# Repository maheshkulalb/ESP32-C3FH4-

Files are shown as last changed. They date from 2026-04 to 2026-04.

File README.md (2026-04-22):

# ESP32-C3FH4 Development Board (External Antenna)

ESP1
ESP2
ESP3

## Overview
This repository contains the complete open-source hardware design for a custom development board based on the Espressif **ESP32-C3FH4** SoC (RISC-V 32-bit single-core, integrated 4MB Flash). 

Unlike standard modules that rely on a PCB trace antenna, this design specifically routes the RF path to an external antenna connector , making it ideal for deployments inside metal enclosures or applications requiring higher-gain antennas. 

## Key Features
* **Microcontroller:** ESP32-C3FH4 (RISC-V 32-bit, 160MHz, built-in 4MB Flash)
* **Connectivity:** 2.4 GHz Wi-Fi and Bluetooth 5 (LE)
* **RF Interface:** connector with impedance-matched 50Ω RF routing
* **USB Interface:** USB Type-C for power and direct Serial flashing
* **Power Supply:** 5V to 3.3V LDO regulator 
* **I/O Breakout:** Standard 2.54mm pitch headers 
* **User Interface:** Reset button, User Boot button (GPIO9)

## EDA Tool & Source Files
This project is designed entirely in **KiCad** 

The native KiCad project files are included, allowing you to modify the schematics, tweak the PCB layout, or export custom manufacturing files.

### Repository Structure
* `/Hardware` - Native KiCad project files (`.kicad_pro`, `.kicad_sch`, `.kicad_pcb`)
* `/Gerbers` - Ready-to-manufacture Gerber and Drill files

**Recommended Fabrication Specs:**
* **Layers:4**
* **Thickness:1.57mm**
* **Impedance Control:Yes**

You are free to use, modify, and distribute this design

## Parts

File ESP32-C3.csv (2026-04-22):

Reference | Qty | Value | DNP | Exclude from BOM | Exclude from Board | Metric | Part Number
C1 | 1 | 1.8pF 6.3V (0.1pF) |  |  |  | Capacitor_SMD:C_0201_0603Metric | CBR02C189B9GAC | *
C2 | 1 | 1.2pF 6.3V (0.1pF) |  |  |  | Capacitor_SMD:C_0201_0603Metric | CBR02C129B9GAC | *
C3 | 1 | 1uF 6.3V 20% |  |  |  | Capacitor_SMD:C_0201_0603Metric | CL03A105MQ3CSNC | *
C4,C6,C7,C20,C21 | 5 | 0.1uF 6.3V 20% |  |  |  | Capacitor_SMD:C_0201_0603Metric | GRM033R60J104ME19D | *
C5 | 1 | 10uF 6.3V 20% |  |  |  | Capacitor_SMD:C_0402_1005Metric | GRM155R60J106ME05D | *
C8 | 1 | 10nF 6.3V 10000pF 10% |  |  |  | Capacitor_SMD:C_0201_0603Metric | GMC02X7R103K6R3NT | *
C9 | 1 | 1uF 6.3V 20% |  |  |  | Capacitor_SMD:C_0201_0603Metric | CL03A105MQ3CSNC | *
C10 | 1 | 1uF 10V 20% |  |  |  | Capacitor_SMD:C_0402_1005Metric | GRM153R61A105ME95D | *
C11 | 1 | 1uF 6.3V 20% |  |  |  | Capacitor_SMD:C_0402_1005Metric | CL05A105MQ5NNNC | *
C14 | 1 | 1uF 6.3V 10% |  |  |  | _0402 | C0402C105K9PACTU | *
C12,C13 | 2 | 9.8pF |  |  |  | Capacitor_SMD:C_0201_0603Metric | CQ0201CRNPO8BN9R8 | *
C15,C16 | 2 | 1pF 5V | DNP |  | Excluded from board | Capacitor_SMD:C_0201_0603Metric
C17 | 1 | 10uF 5V | DNP |  | Excluded from board | Capacitor_SMD:C_0402_1005Metric
C18 | 1 | 10uF 10V 20% |  |  |  | Capacitor_SMD:C_0402_1005Metric | GRM155R61A106ME11D | *
C19 | 1 | 0.1uF 10V 20% |  |  |  | Capacitor_SMD:C_0402_1005Metric | CC0402MRX5R6BB104 | *
CR1,CR2 | 2 | SS14 |  |  |  | ESP32_C3:CR_SMA_403AE_OSI | SS14 | *
CR3 | 1 | SMAJ6.0A |  |  |  | ESP32_C3:SMASeries_LTF-L | SMAJ6.0A | *
D1 | 1 | LTST-C191KFKT |  |  |  | ESP32_C3:LEDC1608X55N | LTST-C191KFKT | *
J1 | 1 | USB4215-03-A |  |  |  | PCB Top Mount, Horizontal, 16Pin | USB4215-03-A | *
J3,J4 | 2 | ***** |  |  |  | ESP32_C3:SAMTEC_TS-110-T-AA | *****
J5 | 1 | CONMHF4-SMD-G-T |  |  |  | ESP32_C3:TE_CONMHF4-SMD-G-T | CONMHF4-SMD-G-T | *
L1 | 1 | 3nH |  |  |  | Inductor_SMD:L_0201_1005Metric | LQP03TN3N0B02D | *
L2 | 1 | 2nH |  |  |  | Inductor_SMD:L_0201_0603Metric | LQP03HQ2N0B02D | *
R1 | 1 | 499R 1% 0.075W |  |  |  | Resistor_SMD:R_0201_0603Metric | TNPW0201499RBEED | *
R2 | 1 | 130R 1% 1/16 |  |  |  | Resistor_SMD:R_0201_0603Metric | CR0201-JW-131GLF | *
R4 | 1 | 0R |  |  |  | Capacitor_SMD:C_0201_0603Metric | CR0201AJ/-000GAS | *
R5,R6,R7,R8 | 4 | 10K 1% 1/20 |  |  |  | Resistor_SMD:R_0201_0603Metric | RC0201FR-0710KL | *
R10,R11 | 2 | 22R 1% |  |  |  | Resistor_SMD:R_0201_0603Metric | ERJ-1GNF22R0C | *
R12 | 1 | 1.5K |  |  | Excluded from board | Resistor_SMD:R_0201_0603Metric
R13,R14 | 2 | 5.1K 1% 1/20 |  |  |  | Res_0201 | RK73H1HTTC5101F | *
S1,S2 | 2 | SKRPABE010 |  |  |  | ESP32_C3:SW_SKRPABE010 | SKRPABE010 | *
U1 | 1 | ESP32-C3FH4 |  |  |  | ESP32_C3:QFN50P500X500X90-33N | ESP32-C3FH4 | *
U2 | 1 | USBLC6-2SC6 |  |  |  | ESP32_C3:SOT95P280X145-6N | USBLC6-2SC6 | *
U3 | 1 | TLV75733PDBVR |  |  |  | ESP32_C3:SOT95P280X145-5N | TLV75733PDBVR | *
Y1 | 1 | XRCGB40M000F1S1LR0 |  |  |  | ESP32_C3:OSC_XRCGB40M000F1S1AR0 | XRCGB40M000F1S1LR0 | *
C_Extra1 |  | 6.8pF +-0.25pF |  |  |  |  | GRM0335C1H6R8CA01D
C_Extra2 |  | 7.8pF |  |  |  |  | GJM0335C1E7R8CB01D
C_Extra3 |  | 8pF |  |  |  |  | GJM0335C1E8R0CB01D
C_Extra4 |  | 8.8pF

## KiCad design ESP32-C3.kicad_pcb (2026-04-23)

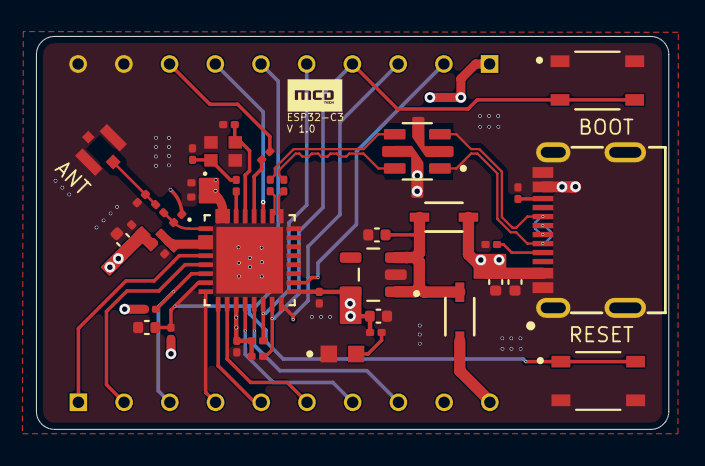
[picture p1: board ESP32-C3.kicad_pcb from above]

Board: 4 copper layers, 35.1 x 21.8 mm, 42 parts (0 on the bottom side), 36 nets.

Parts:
C1: 1.8pF 6.3V; C_0201_0603Metric
C2: 1.2pF 6.3V; C_0201_0603Metric
C3, C9: 1uF 6.3V; C_0201_0603Metric
C4, C6, C7: 0.1uF 6.3V; C_0201_0603Metric
C5: 10uF 6.3V; C_0402_1005Metric
C8: 10nF 6.3V; C_0201_0603Metric
C10: 1uF 10V; C_0402_1005Metric
C11, C14: 1uF 6.3V; C_0402_1005Metric
C12, C13: 9.8pF 6.3V; C_0201_0603Metric
C18: 10uF 10V; C_0402_1005Metric
C19: 0.1uF 10V; C_0402_1005Metric
D1: LTST-C191KFKT; LEDC1608X55N
D2, D3: NSR0320MW2T3G; SOD-323_1P8X1P35_ONS-M
J1: USB4215-03-A; CONN_8p94X6p5X3p16_12L_GCC
J3, J4: TS-110-T-AA; SAMTEC_TS-110-T-AA
J5: CONMHF4-SMD-G-T; TE_CONMHF4-SMD-G-T
L1: 3nH; L_0201_0603Metric
L2: 2nH; L_0201_0603Metric
R1: 499R; R_0201_0603Metric
R2: 130R; R_0201_0603Metric
R4: 0R; C_0201_0603Metric
R5, R6, R7, R8: 10K; R_0201_0603Metric
R10, R11: 22R; R_0201_0603Metric
R13, R14: 5.1K 1%; R_0201_0603Metric
S1, S2: SKRPABE010; SW_SKRPABE010
U1: ESP32-C3FH4; QFN50P500X500X90-33N
U2: USBLC6-2SC6; SOT95P280X145-6N
U3: TLV75733PDBVR; SOT95P280X145-5N
Y1: XRCGB40M000F1S1LR0; OSC_XRCGB40M000F1S1AR0

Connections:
+3V3: C4.1, C5.1, C6.1, C7.1, C8.1, C9.1, C11.1, J3.09, J4.01, L2.2, R2.2, R5.2, R6.2, R7.1, R8.1, U1.11 (VDD3P3_RTC), U1.17 (VDD3P3_CPU), U1.31 (VDDA), U1.32 (VDDA__1), U3.5 (OUT)
+5V: C18.1, C19.1, D2.2 (A), J1.A4/B9 (VBUS), J1.B4/A9 (VBUS), U2.5
/ESP32_C3/0.635 trace: C3.1, L2.1, U1.2 (VDD3P3), U1.3 (VDD3P3__1)
/ESP32_C3/ANT: C2.1, J5.1, L1.2
/ESP32_C3/D0_N: R10.1, U1.25 (GPIO18/USB_D-)
/ESP32_C3/D0_P: R11.1, U1.26 (GPIO19/USB_D+)
/ESP32_C3/D_N: R10.2, U2.6
/ESP32_C3/D_P: R11.2, U2.4
/ESP32_C3/GPIO0: J3.01, U1.4 (GPIO0/XTAL_32K_P)
/ESP32_C3/GPIO1: J3.02, U1.5 (GPIO1/XTAL_32K_N)
/ESP32_C3/GPIO2: J3.03, R7.2, U1.6 (GPIO2)
/ESP32_C3/GPIO3: J3.04, U1.8 (GPIO3)
/ESP32_C3/GPIO4: J3.05, U1.9 (GPIO4/MTMS)
/ESP32_C3/GPIO5: J3.06, U1.10 (GPIO5/MTDI)
/ESP32_C3/GPIO6: J3.07, U1.12 (GPIO6/MTCK)
/ESP32_C3/GPIO7: J3.08, U1.13 (GPIO7/MTDO)
/ESP32_C3/GPIO8: J4.05, R6.1, U1.14 (GPIO8)
/ESP32_C3/GPIO9: J4.04, R5.1, S2.3, S2.4, U1.15 (GPIO9)
/ESP32_C3/GPIO10: J4.03, U1.16 (GPIO10)
/ESP32_C3/GPIO11: J4.02, U1.18 (VDD_SPI/GPIO)
/ESP32_C3/LNA_IN: C1.1, L1.1, U1.1 (LNA_IN)
/ESP32_C3/RST: C14.1, J4.06, R8.2, S1.1, S1.2, U1.7 (CHIP_EN)
/ESP32_C3/U0RXD: J4.07, U1.27 (GPIO20/U0RXD)
/ESP32_C3/U0TXD: J4.08, R1.2
/GPIO/VIN_5V: D3.2 (A), J3.10
/USB/DIN_N: J1.A7 (DN1), J1.B7 (DN2), U2.1
/USB/DIN_P: J1.A6 (DP1), J1.B6 (DP2), U2.3
/USB/VIN: C10.1, D2.1 (K), D3.1 (K), U3.1 (IN), U3.3 (EN)
GND: C1.2, C2.2, C3.2, C4.2, C5.2, C6.2, C7.2, C8.2, C9.2, C10.2, C11.2, C12.2, C13.2, C14.2, C18.2, C19.2, D1.C, J1.A1/B12 (GND), J1.B1/A12 (GND), J1.SH (GND), J4.09, J4.10, J5.2, J5.3, J5.4, R13.2, R14.2, S1.3, S1.4, S2.1, S2.2, U1.33 (GND), U2.2, U3.2 (GND), Y1.2, Y1.4
unnamed: C12.1, R4.1, Y1.1
unnamed: D1.A, R2.1
unnamed: J1.A5 (CC1), R13.1
unnamed: J1.B5 (CC2), R14.1
unnamed: R1.1, U1.28 (GPIO21/U0TXD)
unnamed: C13.1, U1.29 (XTAL_N), Y1.3
unnamed: R4.2, U1.30 (XTAL_P)
